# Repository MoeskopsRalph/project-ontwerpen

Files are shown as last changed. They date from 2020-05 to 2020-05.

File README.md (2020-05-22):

# project-ontwerpen
Alles van project-ontwerpen van de nixie-thermometer.<br>

In de map van Altium staan alle bestanden van Altium inclusief de gerber bestanden.<br>
In de map van AutoCad staat alles van het mechanische ontwerp inclusief een pagina toelichting.<br>
In de map Documentation zijn volgende bestanden toegevoegd samen met foto's: <br>
  -Practical tips<br>
  -Specs<br>
  -user manual<br><br>

link yt video PCB + component: https://www.youtube.com/watch?v=VBEoJwdbBE8&t=5s

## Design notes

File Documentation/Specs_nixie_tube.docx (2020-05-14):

Specifications

Nixie-tube thermometer

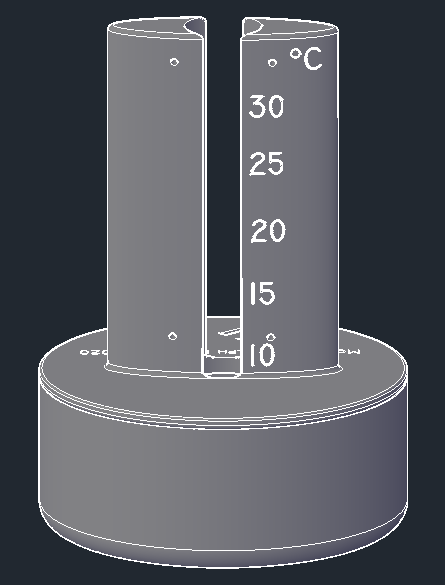
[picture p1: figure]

- The nixie-tube thermometer needs an input voltage of 5V DC through a USB-connector. This connector will be connected to the Arduino nano. This is the only input voltage the thermometer needs.

The nixie-tube will need 150 V but this will be generated within the PCB.

- The current power consumption will vary depending on the temperature. At the lowest the thermometer uses 0,6W and at its peak it will use 1,7W. The thermometer uses +/- 0,9W at 20°C.
- The dimensions are 160mm x 160mm x 220mm. The weight will be around 0,600 kg. The case is printed with a 3D printer in black PLA plastic.
- The range of the temperature is between 10°C and 30°C. The RGB leds have no special use except for the backlighting.
- Warnings:
  - Don’t open the case when it is operating and only use the thermometer when mounted inside the supplied case.
  - Don’t use the thermometer outside because it is not waterproof.
  - Don’t use the thermometer near water for example, near a bath tub. Also the thermometer should be kept out of direct sunlight.
- Caution:
  - Only qualified users can open the case and repair the PCB or replace the nixie-tube. The 150V generated by the thermometer can be a potential danger.
- There will be a 6 months warranty. When there is something broken after shipment, it will be replaced for free.

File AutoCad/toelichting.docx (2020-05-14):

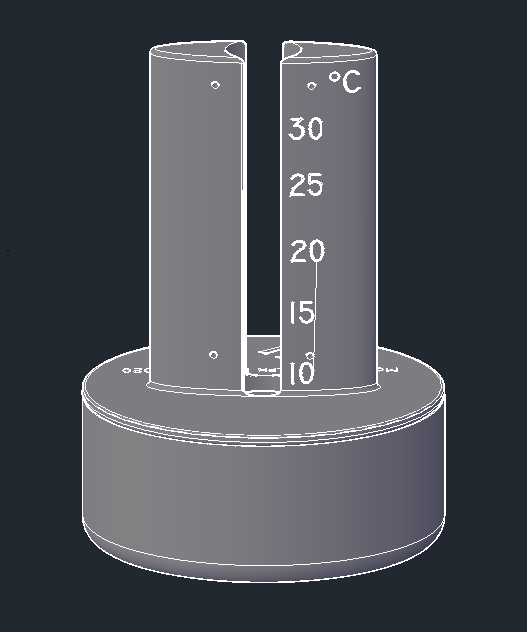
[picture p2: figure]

Mijn project is een nixie-thermometer. Dit is een thermometer die met behulp van een nixie-buis de temperatuur zal weergeven. Mijn pcb is 81mm breed en heeft een lengte van 96mm. Het hoogste component is het Arduino shield. Dit component heeft een totale hoogte van ongeveer 17mm. Hierdoor zal er ruimte voorzien worden boven de pcb. Aan de onderkant van de pcb is een ruimte gelaten van ongeveer 10mm. Dit is voor de verluchting van de pcb zodat het niet te warm kan worden. Ook zijn er 2 gaten voorzien in de cilinder. Het eerste gat dient voor de USB-kabel van de Arduino aan te kunnen sluiten. Het tweede gat is bedoeld voor de temperatuursensor een beetje naar buiten te kunnen brengen zodat de temperatuur veroorzaakt door de pcb en nixie-buis minder invloed gaat hebben op de sensor. In de deksel van de cilinder zijn 2 kleine, schuine rechthoeken geplaatst. Onder deze inkepingen zitten 2 RGB leds, door de schuine inkepingen kan de pcb niet gezien worden als er rechtstreeks wordt naar gekeken. Als de leds branden zal het licht, door de schuine inkepingen gezien worden aan de buitenkant. In het centrum van de deksel is een groter gat gemaakt voor de bekabeling van de nixie-buis. Het gat waar de nixie-buis in wordt geplaatst, is groter dan de buis zelf. Dit is omdat de nixie-buis gevoed wordt met 150V waardoor deze heel snel, heel warm gaat worden. Als dit constant dicht bij de plastiek van de behuizing zit, bestaat de kans dat de plastiek beetje gaat smelten.

Ik heb gekozen voor een cilinder als basis voor het mechanisch ontwerp. Hierdoor gaat het ontwerp er minder standaard uitzien. Minder als een gewone vierkante blok zoals een boterhammendoos. De onderkant is afgerond voor een mooier effect. Aan de binnenkant zijn 4 cilindrische verhogingen gemaakt. Op deze verhogingen zal de pcb geplaatst worden. Ook zit er telkens een gat voor later schroefdraad in te tappen. Hier zal de pcb mee worden vastgeschroefd in de behuizing. Om de deksel en de cilinder op elkaar te plaatsen, heb ik gebruik gemaakt van een kleine trap methode. Doordat de cilinder een kleine inkeping heeft en de deksel beetje uitsteekt, zullen beide zonder problemen op elkaar kunnen worden aangesloten. Ik heb ook gekozen om de deksel en onderkant niet vast op elkaar te bevestigen door een schroef en het gewoon los op elkaar te laten staan. Als ik gebruik zou maken van een schroef zou er altijd een gat te zien zijn aan de bovenkant van de deksel. Een vaste bevestiging is ook niet nodig want de thermometer zal altijd rechtstaan en dient niet om bewogen te worden.

Op de deksel is een ovaal gemaakt die verhoogd is tot de hoogte van de nixie-buis. Vanboven is de ovaal afgerond. Bij de aansluiting van de ovaal en de deksel is ook een afronding gemaakt. Hierdoor is de verbinding steviger maar ook mooier. In het midden van de ovaal is een gat gemaakt voor de nixie-buis. Ook zijn er 2 keer 2 gaten in de ovaal gemaakt. Dit heeft als doel om de nixie-buis te bevestigen. Deze twee bevestigingen zijn bij de nixie-buis geleverd en zijn van een speciaal materiaal gemaakt zodat de plastiek niet te warm gaat worden.

Het volledige ontwerp zal gemaakt worden van PLA of ABS. Dit zijn de meest voorkomende materialen om 3D te printen. De kleur zal zwart zijn. De nixie-buis geeft een oranje kleur dus zwart en oranje zullen mooi bij elkaar passen. Bij een zwarte kleur zal het licht van de leds ook duidelijker te zien zijn dan bij een andere kleur.

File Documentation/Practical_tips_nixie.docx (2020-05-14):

Practical tips, design photos and personal creativity

I chose this project because I am interested in nixie tubes. The nixie tubes have a special effect and distinguish themselves from other lamps. Nixie tubes can be used for a wide variety of projects. This project was meant to get acquainted with nixie tubes and gain more knowledge about it.

The original design from Elektor was built entirely through through-hole components. I have chosen to replace a number of components with SMD components. One part of the PCV takes care of the conversion from 5V to 150V. These components have all been adapted to the SMD variant. This saves space on the PCB and makes the PCB smaller. I also opted for SMD ICs. The only reason is that they are al lot smaller.

At first it seemed like a very easy project, but after a while I found out that working with a nixie tube was not self-evident. The IN-9 nixie tube is not very reliable. They are also only made in Russia, which means that shipping takes a lot of time. There is an IN-13 variant, but these are much more expensive and are even less quickly available. A good tip is to order the nixie tube well in advance in Russia and always take 1 extra as a spare. The nixie tube is made of glass and can break very easily during transport.

In the original design, there were 2 RGB LEDs built in that give light in the holder of the nixie tube. Because it was made of plexiglass, it gave a nice effect. Because our case has to be made with the 3D printer, there is no option to use a transparent material. Therefore I moved the RGB LEDs on the PCB. These will now illuminate the inside of the case, but by making a number of notches in the case, they will still give a nice effect in the black case.

Next time I will try to make a square PCB. That will be easier to make a case for it. Now it was a rectangle which made it less convenient.

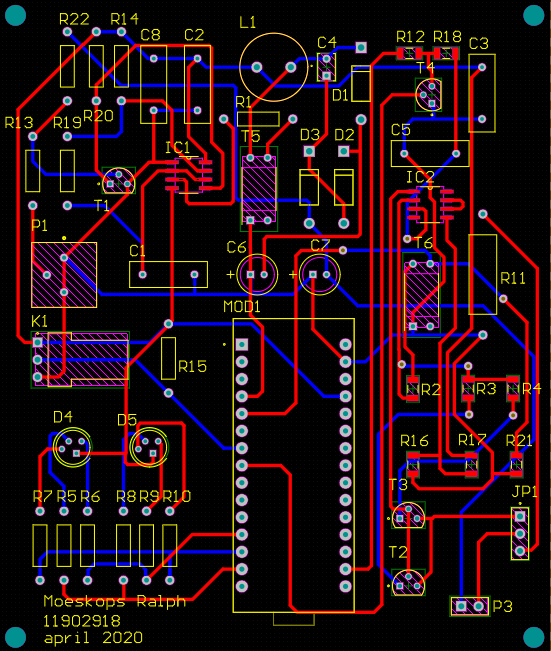
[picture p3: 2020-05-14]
Documentation/pcb_altium.png

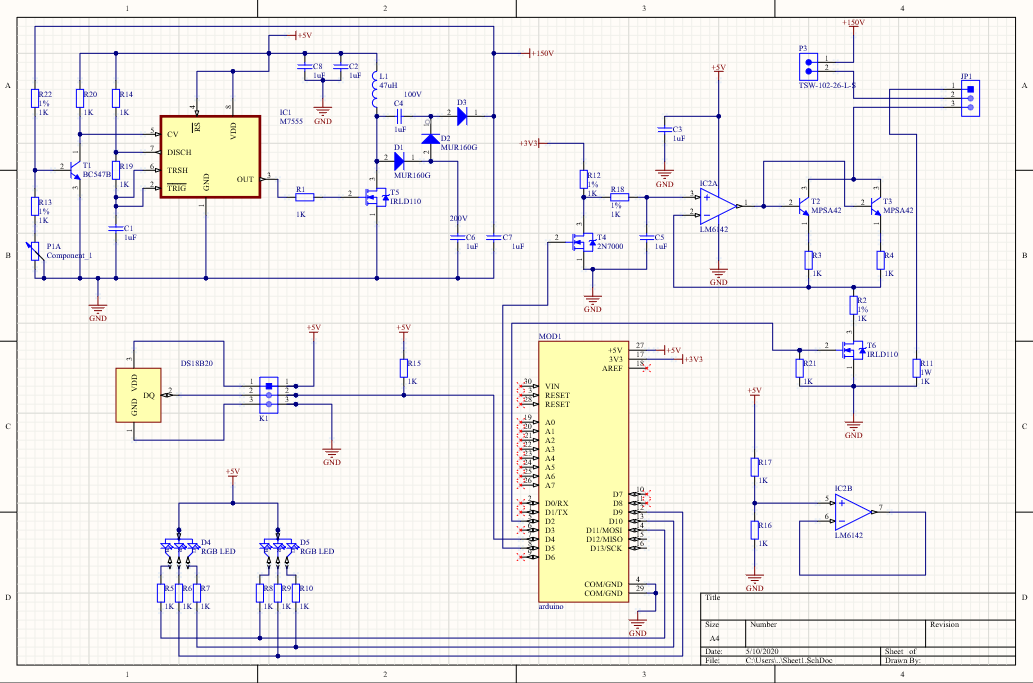
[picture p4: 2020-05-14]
Documentation/schema_altium.png

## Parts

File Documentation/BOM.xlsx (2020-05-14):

BOM nixie_tube | Moeskops Ralph | 1 EAI 2019-2020
Article number | Schematic number | Supplier | Delivery date | Description | Value | Quantity | Price/unit(EUR) | Total price (EUR) | URL
603-CFR-25JT-52-47R | R1 | Mouser electronics | 2020-03-11 | Resistor 47ohm 5% 1/4W Carbon Film | 47 ohm | 1 | €0.09 | €0.09 | https://www.mouser.be/ProductDetail/Yageo/CFR-25JT-52-47R?qs=KUIzHt%2Fe91mCGDfgrZLP2g==
71-CRCW1206150RFKEAC | R2 | Mouser electronics | 2020-03-11 | Resistor - SMD 1/4Watt 150ohms 1% Commercial Use | 150 ohm | 1 | €0.09 | €0.09 | https://www.mouser.be/ProductDetail/Vishay-Dale/CRCW1206150RFKEAC?qs=E3Y5ESvWgWPUd927QfnSDg==
71-CRCW1206220RFKEAC | R3,R4 | Mouser electronics | 2020-03-11 | Resistor - SMD 1/4Watt 220ohms 1% Commercial Use | 220 ohm | 2 | €0.09 | €0.18 | https://www.mouser.be/ProductDetail/?qs=E3Y5ESvWgWOpwN%2FllrABlg==
603-CFR-25JT-52-330R | R5,R6,R7,R8,R9,R10 | Mouser electronics | 2020-03-11 | Resistor 330ohm 5% 1/4W Carbon Film | 330 ohm | 6 | €0.09 | €0.54 | https://www.mouser.be/ProductDetail/Yageo/CFR-25JT-52-330R?qs=KUIzHt%2Fe91mWpUNK8rcuyw==
588-OM8215E-R58 | R11 | Mouser electronics | 2020-03-11 | Resistor 820 Ohm 1W 5% 500 Volt | 820 ohm | 1 | €0.09 | €0.09 | https://www.mouser.be/ProductDetail/Ohmite/OM8215E-R58?qs=AkUtuiJmyfnwcwW3BB7WUg==
71-CRCW12061K00FKEAC | R12 | Mouser electronics | 2020-03-11 | Resistor - SMD 1/4Watt 1Kohms 1% Commercial Use | 1 kohm | 1 | €0.09 | €0.09 | https://www.mouser.be/ProductDetail/Vishay-Dale/CRCW12061K00FKEAC?qs=E3Y5ESvWgWO0OgAK1JT%252BIg==
660-CFS1/4CT52R222G | R13 | Mouser electronics | 2020-03-11 | Resistor 2.2K OHM 2% 1/4W | 2.2 kohm | 1 | €0.12 | €0.12 | https://www.mouser.be/ProductDetail/KOA-Speer/CFS1-4CT52R222G?qs=9IB2bDhijq%2FWHQIXPoYYDA==
660-CFS1/4CT52R332G | R14 | Mouser electronics | 2020-03-11 | Resistor 3.3K OHM 2% 1/4W | 3.3 kohm | 1 | €0.12 | €0.12 | https://www.mouser.be/ProductDetail/KOA-Speer/CFS1-4CT52R332G?qs=sGAEpiMZZMu61qfTUdNhG1dhquwH4o0FZJcjYq5Ujc0=
660-CFS1/4CT52R472J | R15 | Mouser electronics | 2020-03-11 | Resistor 4.7K OHM 5% 1/4W | 4.7 kohm | 1 | €0.21 | €0.21 | https://www.mouser.be/ProductDetail/KOA-Speer/CFS1-4CT52R472J?qs=8x%252BUCq4fY%2FPj%252Bd%252BT9k8WZw==
71-CRCW120610K0FKEAC | R16,R17,R18 | Mouser electronics | 2020-03-11 | Resistor - SMD 1/4Watt 10Kohms 1% Commercial Use | 10 kohm | 3 | €0.09 | €0.27 | https://www.mouser.be/ProductDetail/Vishay-Dale/CRCW120610K0FKEAC?qs=E3Y5ESvWgWNPpaQJSBoFjw==
603-CFR-25JT-52-27K | R19,R20 | Mouser electronics | 2020-03-11 | Resistor 27Kohm 5% 1/4W Carbon Film | 27 kohm | 2 | €0.09 | €0.18 | https://www.mouser.be/ProductDetail/Yageo/CFR-25JT-52-27K?qs=KUIzHt%2Fe91lhrkdPPwYhwg==
71-CRCW1206100KFKEAC | R21 | Mouser electronics | 2020-03-11 | Resistor - SMD 1/4Watt 100Kohms 1% Commercial Use | 100 kohm | 1 | €0.09 | €0.09 | https://www.mouser.be/ProductDetail/Vishay-Dale/CRCW1206100KFKEAC?qs=E3Y5ESvWgWOj0R8WuuRo8w==
660-CF1/4C824J | R22 | Mouser electronics | 2020-03-11 | Resistor 820Kohms 5% | 820kohms | 1 | €0.21 | €0.21 | https://www.mouser.be/ProductDetail/KOA-Speer/CF1-4C824J
652-3386H-1-472LF | P1 | Mouser electronics | 2020-03-11 | Trimmer Resistor - Through Hole 3/8" 4.7Kohms 10% 0.5Watts Square | 4.7 kohm | 1 | €1.40 | €1.40 | https://www.mouser.be/ProductDetail/Bourns/3386H-1-472LF?qs=jh2Y1wKDsmjrvE4Ay%2FFvqQ==
581-SR211A331JAR | C1 | Mouser electronics | 2020-03-11 | Capacitor 100V 330pF 5% C0G | 330pF | 1 | €0.32 | €0.32 | https://www.mouser.be/ProductDetail/AVX/SR211A331JAR/?qs=dAukzdjPV1%252bKdIdI3UL0rQ==
594-K104K10X7RF5UH5 | C2,C3 | Mouser electronics | 2020-03-11 | Capacitor 0.1uF 50volt 10% 5.0mm X7R | 0.1uf 50V | 2 | €0.16 | €0.32 | https://www.mouser.be/ProductDetail/Vishay-BC-Components/K104K10X7RF5UH5?qs=rLgk8CAOBHbAqIwDswVbzA==
539-168104K100H-F | C4 | Mouser electronics | 2020-03-11 | Capacitor 0.1uF 100V 10% | 0.1uf 100V | 1 | €0.95 | €0.95 | https://www.mouser.be/ProductDetail/Cornell-Dubilier-CDE/168104K100H-F?qs=aEuGZpxfbxX1%2FQrsF1S7cw==
594-K105K20X0UF63H5H | C5 | Mouser electronics | 2020-03-11 | Capacitor 1uF 50volts 10% High Temp AEC-Q200 | 1uf 50V | 1 | €0.72 | €0.72 | https://www.mouser.be/ProductDetail/Vishay-BC-Components/K105K20X0UF63H5H?qs=HxuBozqkfXAuIpfy2GWxag==
647-UPS2D2R2MED | C6,C7 | Mouser electronics | 2020-03-11 | Capacitor 200volts 2.2uF 6.3x11 20% 2.5LS | 200V | 2 | €0.26 | €0.52 | https://www.mouser.be/ProductDetail/Nichicon/UPS2D2R2MED?qs=m6DhWUhi0oI6wLzO2BcvyA==
667-EEU-FS2A221 | C8 | Mouser electronics | 2020-03-11 | Capacitor 100VDC 220uF 1800mA Polar | 220uF | 1 | €1.10 | €1.10 | https://www.mouser.be/ProductDetail/Panasonic/EEU-FS2A221?qs=w%2Fv1CP2dgqpx8zM4l%252B3tVw==
863-MUR160G | D1,D2,D3 | Mouser electronics | 2020-03-11 | Diode 600V 1A UltraFast | 600v 1A | 3 | €0.38 | €1.13 | https://www.mouser.be/ProductDetail/ON-Semiconductor/MUR160G?qs=Gev%252BmEvV0ibrrtM3iuYPJA==
604-WP154A43VBDZGCCA | D4,D5 | Mouser electronics | 2020-03-11 | 5MM RGB LED | 5mm rgb | 2 | €1.79 | €3.58 | https://www.mouser.be/ProductDetail/Kingbright/WP154A4SEJ3VBDZGC-CA?qs=YCa%2FAAYMW01T13YiwBKGSw==
610-BC547B | T1 | Mouser electronics | 2020-03-11 | Bipolaire transistors - BJT NPN 50Vcbo 50 Vceo 800mA 625mW Trans | BJT NPN 50V | 1 | €1.13 | €1.13 | https://www.mouser.be/ProductDetail/Central-Semiconductor/BC547B-TIN-LEAD
512-MPSA42 | T2,T3 | Mouser electronics | 2020-03-11 | Bipolaire transistors - BJT NPN Transistor High Voltage | BJT NPN | 2 | €0.40 | €0.79 | https://www.mouser.be/ProductDetail/ON-Semiconductor-Fairchild/MPSA42?qs=UMEuL5FsraDu%2F9ZWGlN1JQ==
512-2N7000 | T4 | Mouser electronics | 2020-03-11 | MOSFET N-CHANNEL 60V 200mA | 60V 200mA | 1 | €0.32 | €0.32 | https://www.mouser.be/ProductDetail/ON-Semiconductor/2N7000?qs=FOlmdCx%252BAA2o%2FKZOTk%2F3hg==
844-IRLD110PBF | T5,T6 | Mouser electronics | 2020-03-11 | MOSFET N-CH 100V HEXFET MOSFET HEXDI | 100V | 2 | €0.83 | €1.66 | https://www.mouser.be/ProductDetail/844-IRLD110PBF
968-ICM7555CBAZ | IC1 | Mouser electronics | 2020-03-11 | IC SMD GEN PURPSE CMOS TIMR COM | smd cmos | 1 | €0.64 | €0.64 | https://www.mouser.be/ProductDetail/Renesas-Intersil/ICM7555CBAZ
926-LM6142AIMX/NOPB | IC2 | Mouser electronics | 2020-03-11 | IC SMD Opamp | smd opamp | 1 | €5.62 | €5.62 | https://www.mouser.be/ProductDetail/Texas-Instruments/LM6142AIMX-NOPB
700-DS18B20+ | DS18B20 | Mouser electronics | 2020-03-11 | Programmable Resolution 1-Wire Digital Thermometer | Thermometer | 1 | €3.53 | €3.53 | https://www.mouser.be/ProductDetail/Maxim-Integrated/DS18B20+?qs=7H2Jq%252ByxpJKegCKabDbglA==
710-61900319521 | K1 | Mouser electronics | 2020-03-11 | Headers & Wire Housings WR-WTB 2.54mm Male 3Pin RtAgld TopLckg | 2.54mm male 3pin | 1 | €0.64 | €0.64 | https://www.mouser.be/ProductDetail/Wurth-Elektronik/61900319521?qs=W%252B2sBeLta1aDTvsFG9eNEw==
710-61900311621 | P3 | Mouser electronics | 2020-03-11 | Headers & Wire Housings WR-WTB 2.54mm Female 3Pin Terminal Hsng | 2.54mm female 3pin | 1 | €0.12 | €0.12 | https://www.mouser.be/ProductDetail/Wurth-Elektronik/61900311621?qs=W%252B2sBeLta1YzXaI7AwpZrg==
855-M20-7820842 | MOD1 | Mouser electronics | 2020-03-11 | Headers & Wire Housings 8 PIN SIL VERTICAL SOCKET GOLD+TIN | 8 pin sil vertical socket | 4 | €0.99 | €3.96 | https://www.mouser.be/ProductDetail/Harwin/M20-7820842?qs=WS5Jv%252B%252Bx1qXOep0XOTvy2Q==
22-28-4033 | JP1 | Mouser electronics | 2020-03-11 | Header TH 3PINS header | 3pins | 1 | €0.23 | €0.23 | https://www.mouser.be/ProductDetail/Molex/22-28-4033?qs=d9fIA1aNikRRpuevshfBIQ==
IN-9 tube | IN-9 | Tubes-store | 2020-03-10 | Nixie-tube | / | 1 | €7.35 | €7.35 | https://www.tubes-store.com/product_info.php?products_id=307
ABX00028 | MOD1 | Mouser electronics | 2020-03-11 | Arduino Nano | / | 1 | €10.43 | €10.43 | https://www.digikey.be/product-detail/nl/arduino/ABX00028/1050-ABX00028-ND/10239971
ELC08D470E | L1 | rs-online | 2020-04-06 | Inductor 471uF/1,2A | 471uF | 1 | €1.11 | €1.11 | https://benl.rs-online.com/web/p/leaded-inductors/1101300/
 |  |  |  |  |  |  | Total (excl. VAT) | €49.85
 |  |  |  |  |  |  | Total (incl. VAT) | €60.32

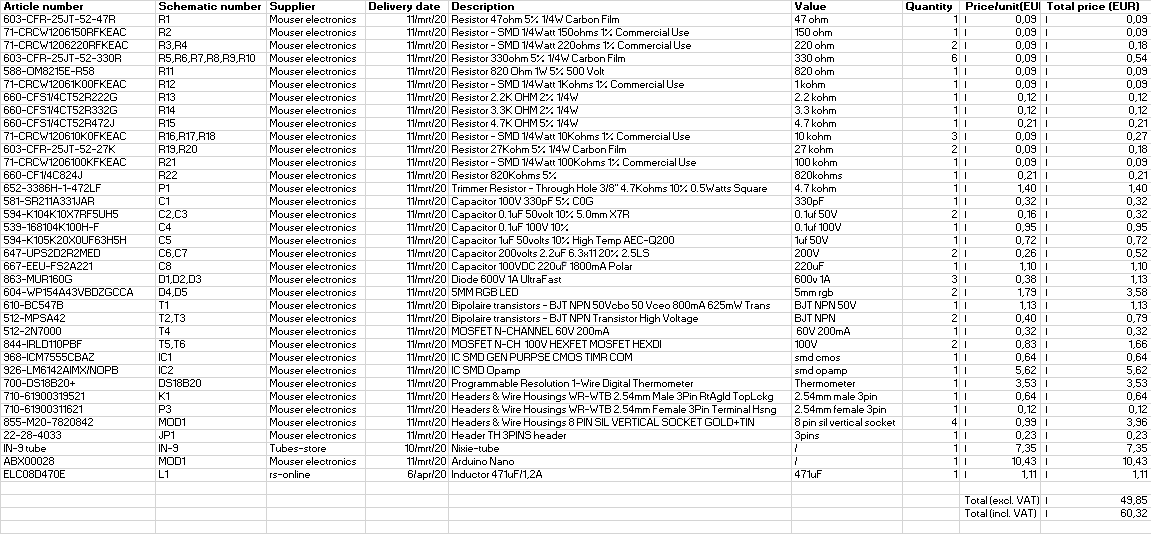
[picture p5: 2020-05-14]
Documentation/BOM.png

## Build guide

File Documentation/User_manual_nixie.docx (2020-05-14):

User manual


The nixie-thermometer will display the temperature on a nixie-tube. Depending on the temperature, it will heat up and give off an orange glow. A temperature sensor will collect data and transmit it to the Arduino. This data is viewed and analyzed by the Arduino Nano. Next the Arduino will calculate what voltage must be applied to the nixie tube. As the voltage increases, the orange glow will rise.

A number of LEDs will also be connected, these serve purely for decoration. To make sure the color of the RGB LEDs is visible on the outside, there are holes in de lateral aspects of the case. The LED’s will give a nice effect on the outside of the housing.

The nixie-thermometer is very simple to use. You only have to plug the USB-cable in the Arduino and plug the USB-cable into your computer or a USB socket. The Arduino is pre-programmed so there is nothing else you have to do.

It will take a few minutes for the temperature sensor to be correctly. After a few minutes the nixie-thermometer will be operational.

If the nixie-thermometer is active, don’t touch the tube. This can be very hot and you can get burns.

When choosing a place for the thermometer you will have to take into account the temperature and air flow. Avoid, for example, placing your thermometer above an electric heater. This because the hot air will rise up and interfere with the thermometer’s reading.

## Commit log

2020-03-02 update schema
    [Components - 01.03.20 - 17.24.PcbLib, Components - 01.03.20 - 17.24.SchLib, Components - 28.02.20 - 11.56.PcbLib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]
2020-04-28 Gerber bestanden toegevoegd
2020-05-14 Toevoegen Documentation en Autocad
    [BOM.xlsx]
2020-05-15 Powerpoint toegevoegd
